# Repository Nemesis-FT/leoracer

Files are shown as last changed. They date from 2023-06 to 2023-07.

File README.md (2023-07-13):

# leoracer
> Now [THIS](https://youtu.be/8bLkcCZFKvA) Is Podracing

[See the controller in action!](https://youtu.be/5lz1fPlmYiA)
Alt The leoracer controller, ready to be used

Leoracer is a making project that aims to create an alternative game controller for the now long forgotten [Pod Racer Game](https://en.wikipedia.org/wiki/Star_Wars_Episode_I:_Racer) developed by LucasArts and recently made available for modern Windows machines through [GoG](https://www.gog.com/en/game/star_wars_episode_i_racer).  
The controller features a double airplane-throttle layout, which can tilt forwards (thus handling the pod's thrust) and tilt sideways (thus handling the pod's tilting): in order to turn left, the player has to reduce throttle to the right side, and vice versa.  
All of this is to provide a more "realistic" control scheme through a D-Input compliant controller, and this is achieved by using the great [ArduinoJoystickLibrary](https://github.com/MHeironimus/ArduinoJoystickLibrary) created by Matthew Heironimus. Kudos to him for the great work he's done on this library. 

This project has been developed for the course "Laboratory of Making" taught by Professor Renzo Davoli and Professor Federico Montori at the University of Bologna, Alma Mater Studiorum.

## Required components
The provided links are provided just for guidance in part-picking. I am not affiliated with "futuranet" or other vendors and I'm not sponsoring them in any way, it's just the store that I used for this project to gather parts.
* An Arduino Leonardo and the Arduino IDE;
* At least 4 variable resistors (I highly suggest you buy spares just in case you damage them during soldering) like this [one](https://futuranet.it/prodotto/potenziometro-lineare-1-kohm/);
* 2 arcade-style buttons like this [one](https://futuranet.it/prodotto/pulsante-arcade-corto-blu/);
* 1 button like this [one](https://futuranet.it/prodotto/pulsante-da-pannello-normalmente-aperto-nero/);
* 1 toggle switch like this [one](https://futuranet.it/prodotto/deviatore-on-on-a-levetta-cs-90/);
* Male to male patch wires and male to female patch wires;
* Some electrical wires;
* PCBs terminal blocks;
* M3 screws of different lenghts;
* M3 brass screw sockets;
* 9 suction cups like this [ones](https://www.amazon.it/dp/B084BRH8GP?psc=1&ref=ppx_yo2ov_dt_b_product_details);
* Soldering equipment;
* A multimeter for troubleshooting;
* A 3D printer or a friend with a 3D printer.

## Building the controller
1. Print all the parts, keeping in mind that the two sides share all the components except for the external shell (BodyR and BodyL). I've used a Lotmaxx SC-10 Shark with some random PLA and all of them have printed nicely;
2. Solder all the components to jumper/patch wires, and embed the brass sockets in the prints using the solderer;
3. Assemble all the parts according to the [animation](https://drive.google.com/file/d/1N2wPsxAuo81091dKuf4QRvu4FyjoekB1/view?usp=sharing), which does not include assembly of the buttons, screws and corresponding sockets.;
4. Connect all the wires to the arduino accordingly to the electrical schema;
5. Flash the Arduino Leonardo with the calibration software: to calibrate the controller, move the axises from minimum to maximum in this order: Right Throttle, Right Tilt, Left Tilt, Left Throttle (after each movement, press the right throttle button);
6. Flash the Arduino Leonardo with the firmware, hopefully you should see your controller on your PC (remember to download and add to Arduino IDE the [ArduinoJoystickLibrary](https://github.com/MHeironimus/ArduinoJoystickLibrary)).

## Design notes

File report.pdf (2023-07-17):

July 13, 2023

# Leoracer

Lorenzo Balugani
Master's Degree student @ Alma Mater Studiorum - University of Bologna

## Contents

## 1 Introduction

This document serves as the project report for the Leoracer project, which was created for the Alma Mater Studiorum’s “Laboratory of Making” course, held by Professor Renzo Davoli and Professor Federico Montori in 2023.

This report will contain information pertinent to the project, such as the problem description, the implementation and development process description and the summary of the issues that have arisen during the project lifecycle. Additionally, it will contain a section all about future improvements.

Special thanks to Matthew Heironimus for his joystick library [2], that was key in the development of this project.

## 2 The problem and the solution

This project aims at solving a very specific and obscure issue that may be of not a lot of interest to many, but it’s still an useful exercise as a first project that involves electronics, 3D design and 3D printing.

Leoracer is a purpose made controller that aims to make available to everyone that possesses the correct equipment to experience the arcade version of the videogame “Star Wars Episode 1: Racer”: the arcade machine wasn’t extremely widespread when it was created, and as time passes it has become more and more rare.

Before going too much in depth, let’s understand what’s the game about in the first place, and what made the arcade version stand out. In the game, the player controls one of the several “Pod Racers” in different races around the galaxy, hence this game behaves for the most part as a racing game. The pod racers are vehicles propelled by several engines, and canonically they “turn” by lowering the thrust of half of the engines, like an airplane moving on the ground. Other than turning, the pod racers can tilt on their axis and pull their nose up or down to better handle air time.

In the computer release and on the console ones, the control over the pod is provided by keyboard, mouse or the analog sticks of the controller. In the arcade version, as portrayed in [1], the user is given two throttle controls that can be manipulated in order to make the vehicle change direction, being the key stand-out feature of the arcade release, along with better graphics.

Leoracer was hence developed in order to bring this control scheme to the PC release, while trying to improve the original product. Leoracer’s throttle control can tilt forwards/backwards and sideways, allowing the user to not just control the thrust and the direction, but also the pod racer’s tilt. The controller features 3 buttons, one of which is also mapped as the combination of both throttle buttons and a toggle, that allows the control of the pod’s orientation.

## 3 Developing the solution

### 3.1 3D Modeling

In order to create such a particular controller, a custom model was needed. The design was made using Solidworks, a powerful parametric CAD software aimed at mechanical 3D modeling. Using Solidworks allowed, through its constraints system, to test the design before printing: this allowed the resolution of many issues before printing the components, and guaranteed the alignment of screw holes and etcetera.

The main inspiration for the controller was a radio transmitter for RC planes, that had two analog sticks that behaved in the desired way. The final design is basically a cylinder with a missing section of its surface, allowing the throttle to be mounted on a potentiometer - allowing it to tilt in all the needed directions.

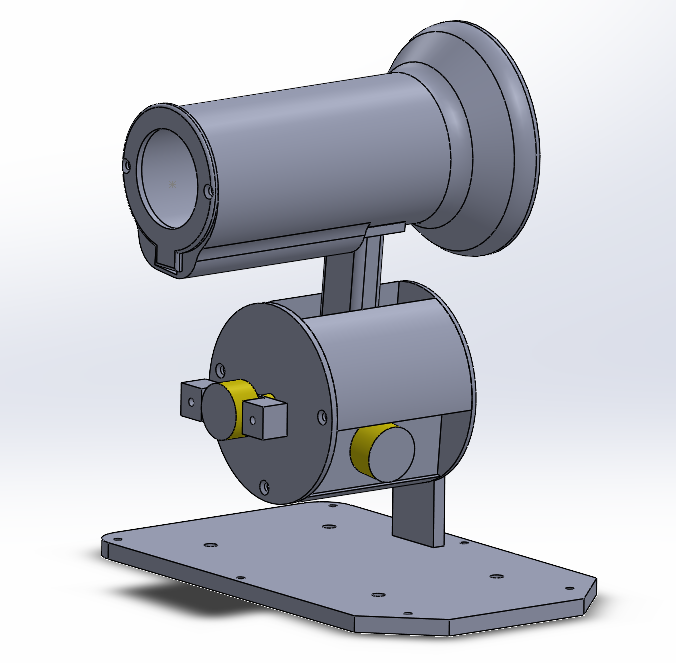
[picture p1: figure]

Figure 1: The rotating cylinder of the throttle

The cylinder is held in place both by the potentiometer that handles forward tilting - which attaches to the external case - and a holder that sits on top of the bottom of the controller.

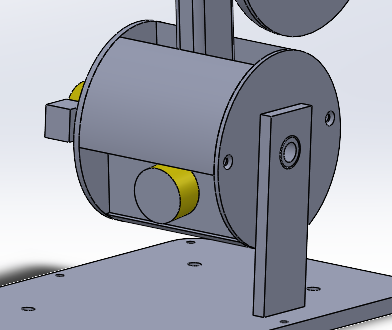
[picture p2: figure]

Figure 2: The support for the rotating cylinder

The throttle is made of two components: the “stick” and the “handle” itself. Both allow a wire to be routed inside of them, which will connect to the button placed inside the handle, and exit from the cylinder using the hole that can be seen fn figure 2. The staff is locked in place by a screw, that is inserted on the larger side of the handle.

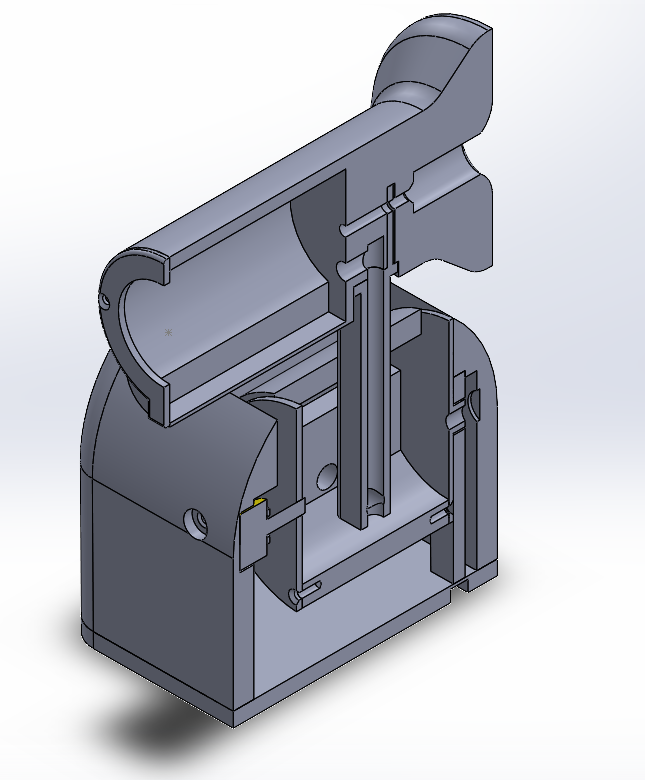
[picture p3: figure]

Figure 3: A slice of the controller, showing the button’s wire channel

Due to the nature of the controller, two throttles will be needed. These are symmetrical internally, while externally they have a slightly different case.

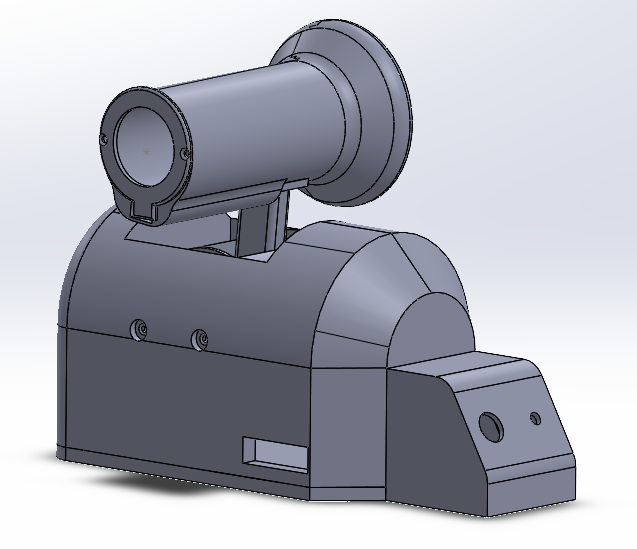
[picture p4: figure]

Figure 4: The right part of the controller

The Arduino Leonardo can fit inside the case of the right part of the controller.

### 3.2 3D Printing

All the parts were printed on a Lotmaxx SC-10 Shark, a FDM 3D printer. In order to make all components stick together, brass screw inserts were embedded - with the help of a soldering iron - in the provided holes of all the prints, and M3 screws were used. The controller is held in place on the table by small suction cups.

### 3.3 Circuit design

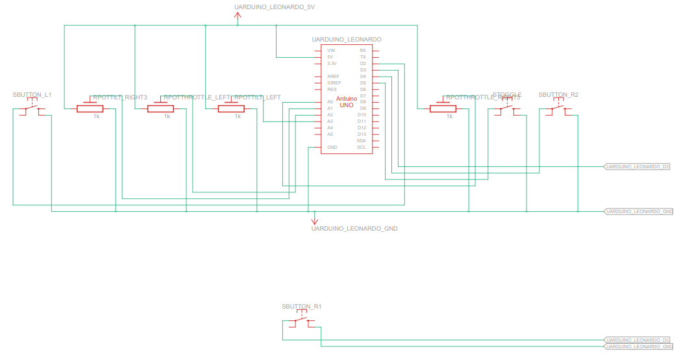
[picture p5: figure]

Figure 5: The schema of the controller

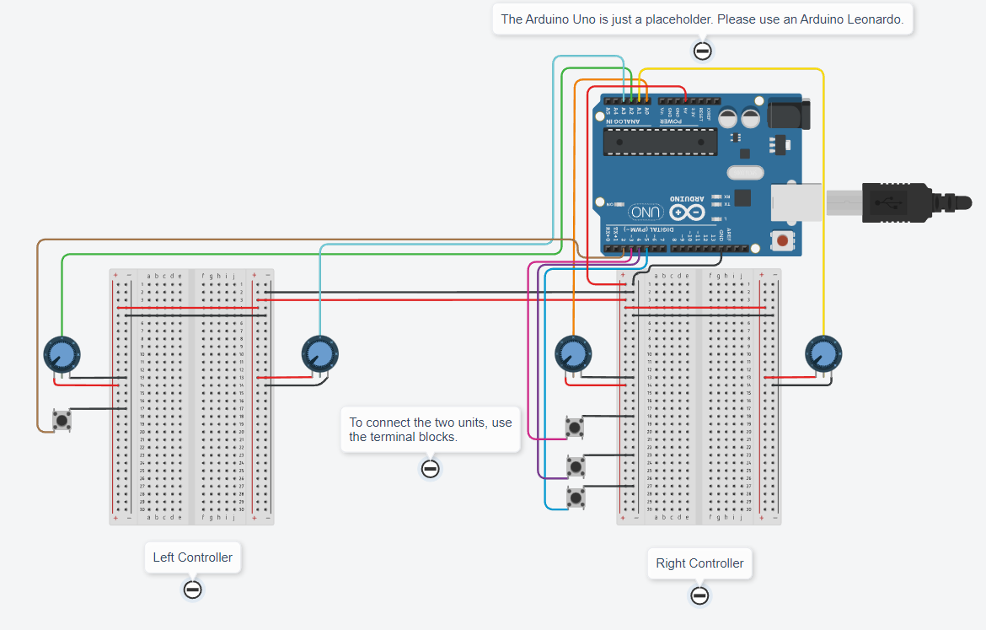
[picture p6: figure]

Figure 6: An intuitive version of the schema

The circuit requires to solder just the buttons, the resistors and the terminal blocks that connect the two parts, and all other connections can be made using jumper wires and breadboards. Additionally, a custom cable needs to be made to connect both parts of the controller. Since the Arduino is configured with INPUT_PULLUP, the buttons do not require resistors to properly work.

### 3.4 Firmware development

Two different pieces of firmware have been developed: the main firmware, which is the one that interfaces with a PC as a D-Input device, and the calibrator, which assists with the calibration routine.

### 3.4.1 Calibrator

The calibrator allows the user to calibrate the controller by placing one axis at a time at its maximum or minimum, then pressing the right throttle button. The calibration data gets then saved to the EEPROM, and will get loaded by the controller firmware. The calibration order is at it follows:
1. Right Throttle (Min/Max).
2. Right Tilt (Min/Max).
3. Left Tilt (Min/Max).
4. Left Throttle (Min/Max).

### 3.4.2 Controller

The controller firmware hevily relies on the Arduino Joystick Library [2], that allows him to act as any D-Input controller, with many customizable parameters. The firmware loads calibration data from the EEPROM, and then uses it to map each axis to a percentage. The axis are evaluated as it follows:
- X-Axis (turning): percentages of the two throttle potentiometers are subtracted, and the resulting value gets passed as the value of the X axis;
- Y-Axis (attitude): the toggle status gets evaluated, and Y is set to the maximum or the minimum, accordingly;
- Z-Axis (throttle): the highest percentage of the two throttle potentiometers gets used;

For tilting, two buttons (4 and 5) are used, since the game consideres it a discrete value. If the two tilt controls have a percentage lower than 15 (or higher than 85), the corresponding button gets pressed.

## 4 Using the controller

Once built and calibrated, the controller is straightforward to use, as it gets picked up as a standard D-Input controller. The buttons can be bound ingame without much of an issue. A video of the game being played with the controller can be seen on Youtube [3].

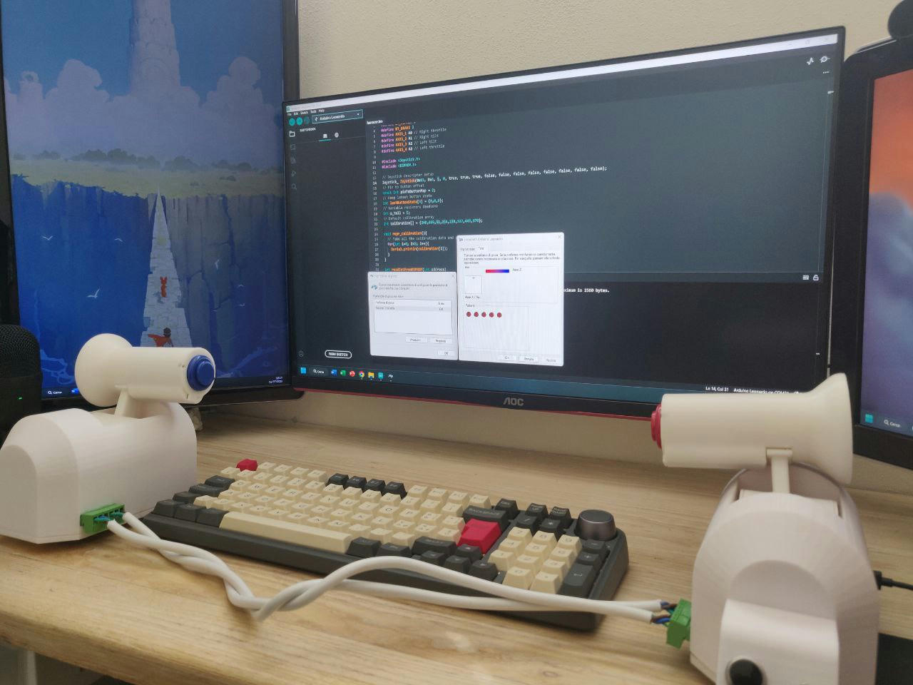
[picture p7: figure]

Figure 7: The Leoracer Controller

## 5 Project availability

The project is available under the GPL v3 license on the github repository [4]. The readme contains a detailed parts list and a set of instruction for assembly.

## 6 Challenges

This project was the first experience with developing from scratch and printing a complex model that had to accomplish some mechanical challenges. It also was the first project that involved soldering and - in general - electronics.

## 7 Known issues

- Due to how the in-race menu works, it’s not possible to control it using the keyboard, as it’s meant to be controlled by the Y axis of the controller. In order to regain control, press CTRL+J to momentarely disable controller input.
- Suction cups do not work on all surfaces.

## 8 Future improvements

The controller, as is, works great. However, several improvements could be made in a future revision, such as:
- Encoders instead of potentiometers, providing better accuracy and longevity.
- More buttons on the throttle handles, in order to increase button count.
- Stiffer throttle tilting, perhaps achieved using springs.
- Reduced bulkyness of the case.
- An optional mountuing system to allow the controller to stick to any surface.

## Bibliography

[1] Dr. Retro. Star Wars Episode 1 Arcade Racer Cabinet Gameplay, (2014). [Online Video]. Available: https://www.youtube.com/watch?v=g0bF3kAVur4
[2] Matthew Heironimus, “Arduino joystick library.” [Online]. Available: https://github.com/MHeironimus/ArduinoJoystickLibrary (https://github.com/MHeironimus/ArduinoJoystickLibrary)
[3] Lorenzo Balugani. Star Wars Episode 1 Racer With a Custom Controller, (2023). [Online Video]. Available: https://www.youtube.com/watch?v=g0bF3kAVur4
[4] Lorenzo Balugani, “Leoracer repository.” [Online]. Available: https://github.com/Nemesis-FT/leoracer (https://github.com/Nemesis-FT/leoracer)

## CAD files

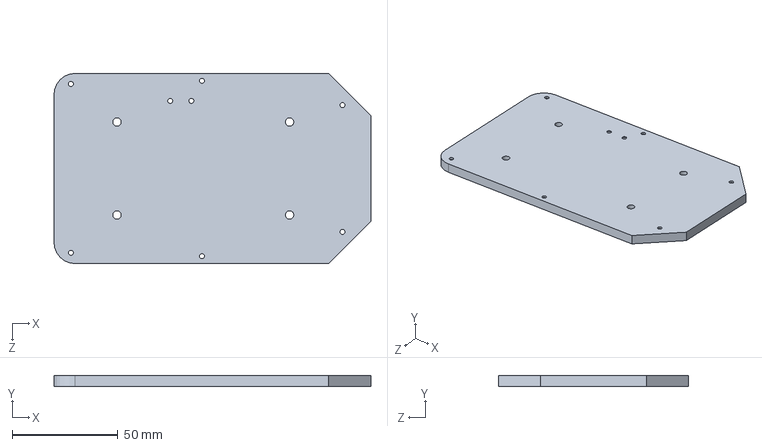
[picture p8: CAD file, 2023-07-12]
cad files/Base.SLDPRT
150.0 x 5.00 x 90.0 mm

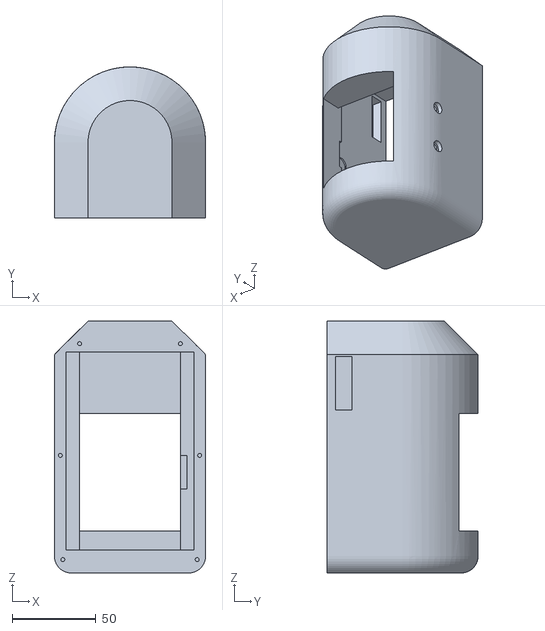
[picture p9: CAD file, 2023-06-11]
printables/BodyL.STL
90.0 x 90.0 x 150.0

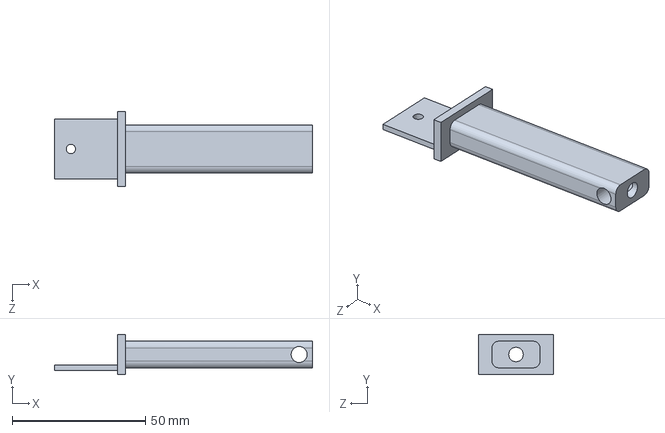
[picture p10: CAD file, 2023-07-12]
cad files/Staffa.SLDPRT
96.7 x 15.0 x 28.0 mm

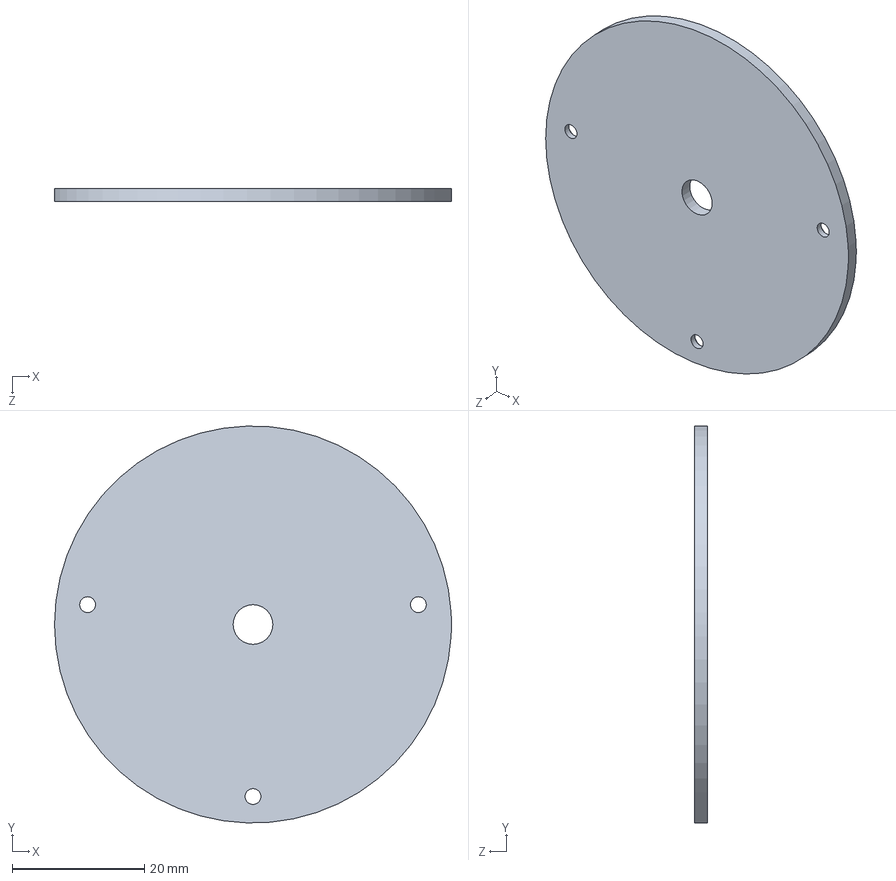
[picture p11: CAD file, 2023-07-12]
cad files/RollerTappo.SLDPRT
60.0 x 60.0 x 2.00 mm

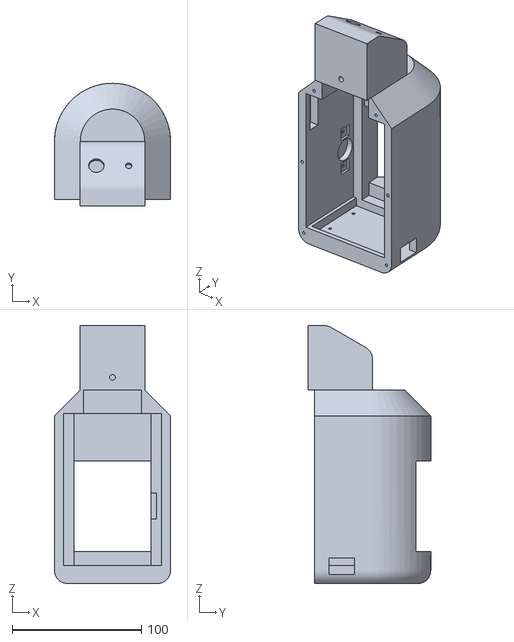
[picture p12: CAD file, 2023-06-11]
printables/BodyR.STL
90.0 x 95.0 x 200.0

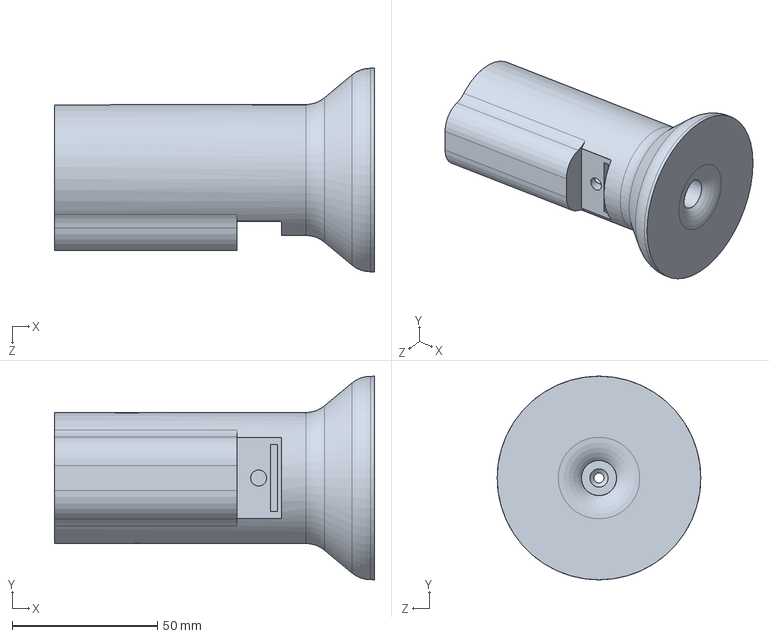
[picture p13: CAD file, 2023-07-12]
cad files/Handle.SLDPRT
110.0 x 70.0 x 70.0 mm

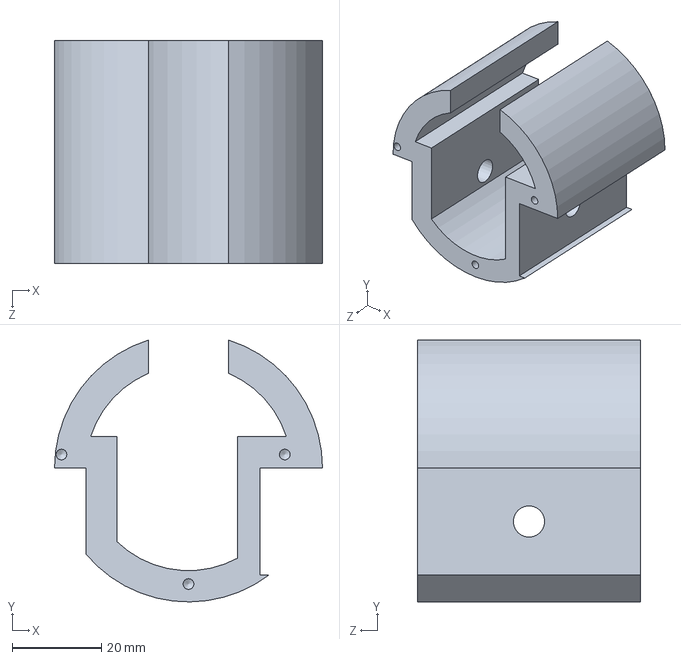
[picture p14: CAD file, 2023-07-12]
cad files/Rollerv2.SLDPRT
60.0 x 58.6 x 50.0 mm

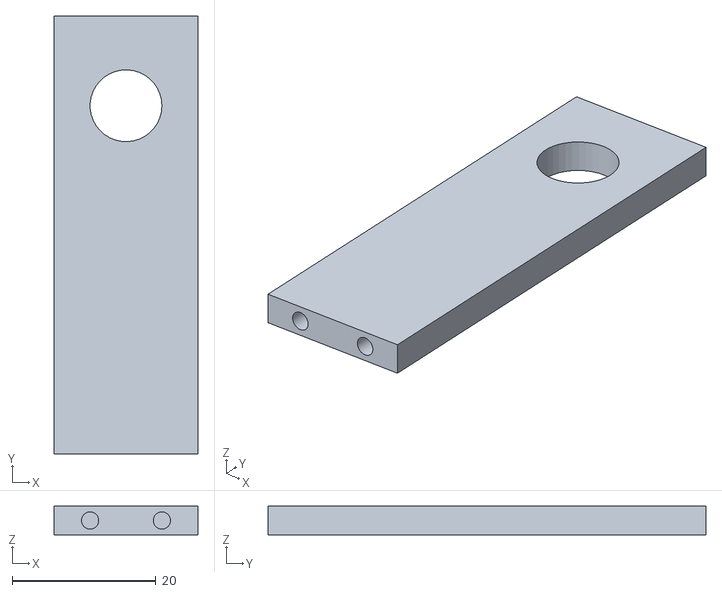
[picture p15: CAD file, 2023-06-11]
printables/BodyPilastrino.STL
20.0 x 61.0 x 4.00

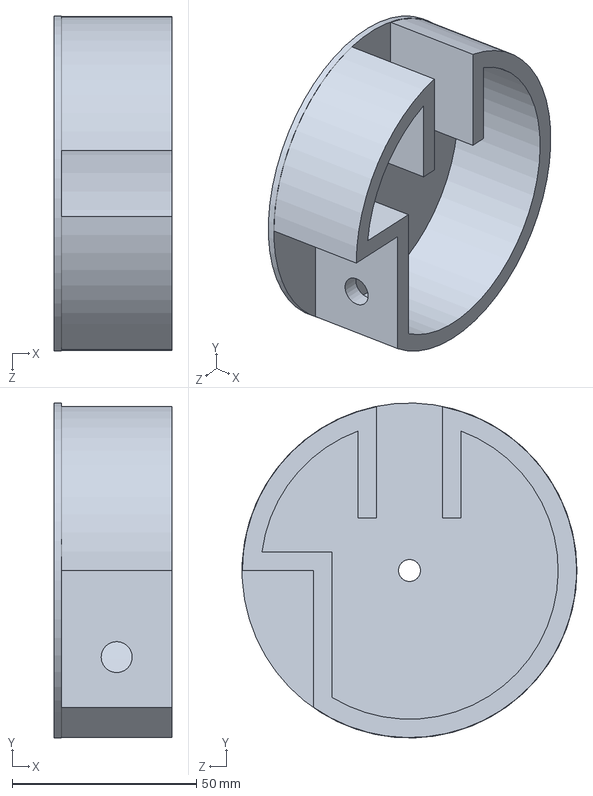
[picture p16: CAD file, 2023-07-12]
cad files/Roller.SLDPRT
32.0 x 91.0 x 91.0 mm

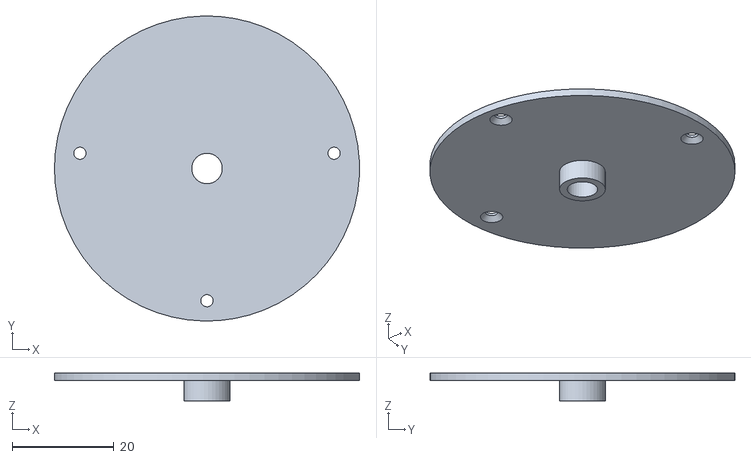
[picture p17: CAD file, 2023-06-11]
printables/RollerTappo2.STL
60.0 x 60.0 x 5.50

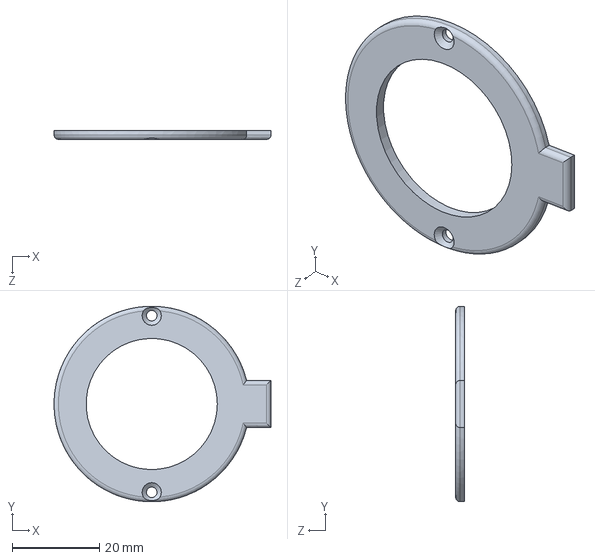
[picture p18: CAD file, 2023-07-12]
cad files/HandleButtonHolder.SLDPRT
49.6 x 44.7 x 2.00 mm

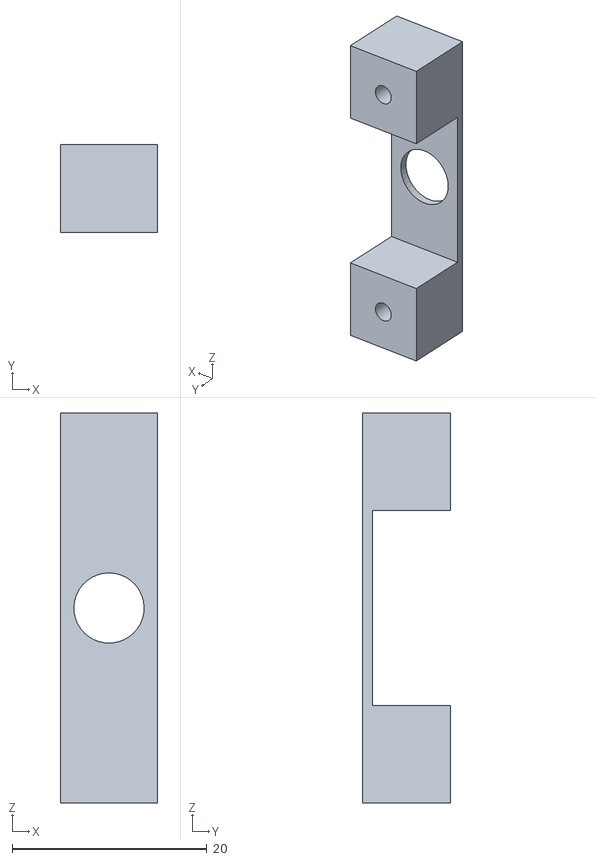
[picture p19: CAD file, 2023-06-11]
printables/HolderResistore.STL
10.0 x 9.00 x 40.0

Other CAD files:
printables/Base.STL
printables/Staffa.STL
printables/Rollerv2.STL
cad files/Bodyl.SLDPRT
cad files/HolderResistore.SLDPRT
printables/HandleButtonHolder.STL
cad files/ArduinoLeonardo.SLDPRT
cad files/Body.SLDPRT
cad files/BodyPilastrino.SLDPRT
cad files/RollerTappo2.SLDPRT
printables/Handle.STL
printables/RollerTappo.STL

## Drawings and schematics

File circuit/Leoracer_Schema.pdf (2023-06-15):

A

1 | 2 | 3 | 4 | 5 | 6

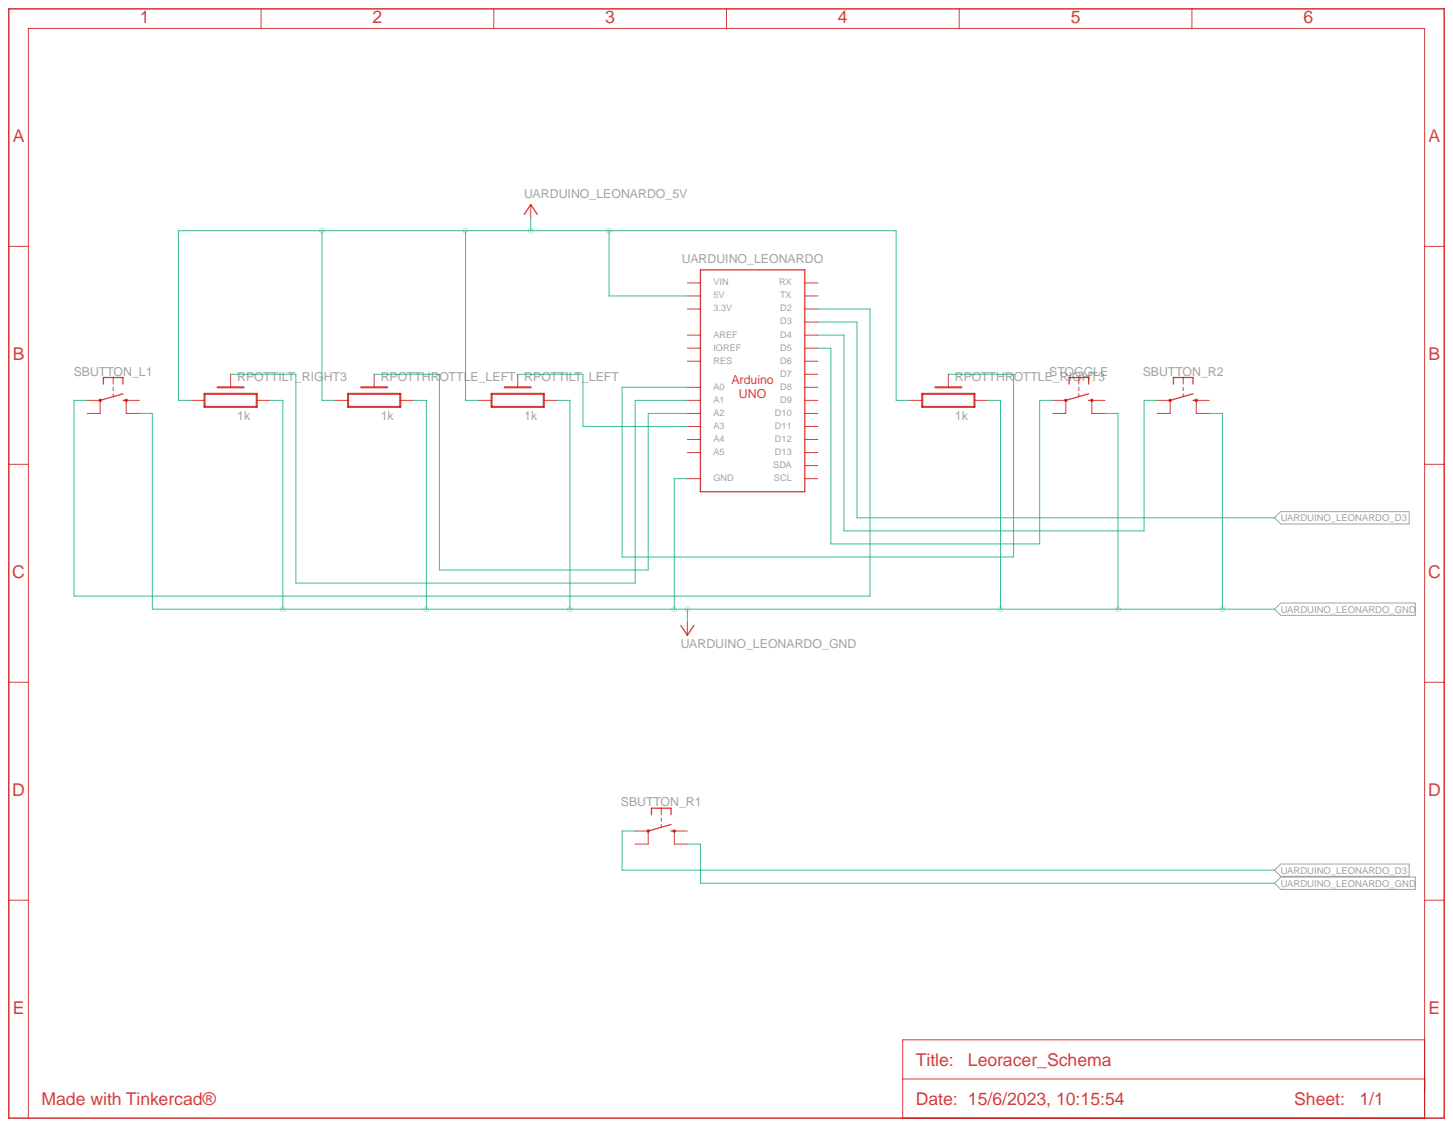
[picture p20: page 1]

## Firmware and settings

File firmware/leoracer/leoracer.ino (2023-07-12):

#define BT_TOGGLE 5
#define BT_WARP 4
#define BT_REPAIR 3
#define BT_BRAKE 2
#define AXIS_1 A0 // Right throttle
#define AXIS_2 A1 // Right tilt
#define AXIS_3 A2 // Left tilt
#define AXIS_4 A3 // Left throttle

#include <Joystick.h>
#include <EEPROM.h>

// Joystick descriptor setup
Joystick_ Joystick(0x03, 0x4, 5, 0, true, true, true, false, false, false, false, false, false, false, false);
// Pin to Button offset
const int pinToButtonMap = 2;
// Keep latest button state
int lastButtonState[4] = {0,0,0};
// Variable resistors deadzone
int p_toll = 5;
// Default calibration array
int calibration[] = {240,440,55,254,150,327,449,670};

void repr_calibration(){     
  // Take all the calibration data and print it out         
  for(int i=0; i<8; i++){
    Serial.println(calibration[i]);
  }
}

int readIntFromEEPROM(int address)
{
  // Read two bytes from the starting address
  byte byte1 = EEPROM.read(address);
  byte byte2 = EEPROM.read(address + 1);
  return (byte1 << 8) + byte2;
}


void read_calibration(){
  // Calibration loader
  Serial.println("Attempting data load from EEPROM...");
  int tmp;
  for(int i=0; i<16; i=i+2){
    calibration[i/2] = readIntFromEEPROM(i);;
  }
  Serial.println("Calibration data loaded from EEPROM.");
  repr_calibration();
}

void setup() {
  // I/O setup
  pinMode(BT_WARP, INPUT_PULLUP);
  pinMode(BT_REPAIR, INPUT_PULLUP);
  pinMode(BT_TOGGLE, INPUT_PULLUP);
  pinMode(BT_BRAKE, INPUT_PULLUP);
  pinMode(AXIS_1, INPUT);
  pinMode(AXIS_2, INPUT);
  pinMode(AXIS_3, INPUT);
  pinMode(AXIS_4, INPUT);
  Serial.begin(9600);
  delay(1000);
  read_calibration();
  Joystick.setXAxisRange(-100, 100);
  Joystick.setYAxisRange(0, 1);
  Joystick.setZAxisRange(0, 100);
  Joystick.begin();
}

void handle_buttons(){
  // Button handling function, with override for button doublepress
  bool override = false;
  // Get the state
  for (int index = 0; index < 3; index++)
  {
    int currentButtonState = !digitalRead(index + pinToButtonMap);
    if (currentButtonState == HIGH)
    {
      
      lastButtonState[index] = currentButtonState;
    }
    else{
      
      lastButtonState[index] = currentButtonState;
    }
  }
  // Apply the state
  for(int index = 0; index < 3; index++){
    if(index == 0 && lastButtonState[0] && lastButtonState[1]){
      Joystick.setButton(2,1);
      Joystick.setButton(1,0);
      Joystick.setButton(0,0);
      override = true;
      break;
    }
    else{
      Joystick.setButton(index, lastButtonState[index]);
    }
    
  }
}

int to_percent(int min, int max, int value){
  // map the value to a percentage
  return map(value, min, max, 0, 100);
}

int handle_y(){
  // handle Y axis (which is considered as on/off since its wired to a toggle)
  int currentButtonState = !digitalRead(BT_TOGGLE);
  if (currentButtonState)
  {
    return 1;
  }
  return 0;
}

int handle_x(int perc_l, int perc_r){
  // handle X axis by comparing percentage of the throttles
  if(perc_l-p_toll < perc_r && perc_l+p_toll > perc_r){
    return 0;
  }
  else if (perc_r-p_toll < perc_l && perc_r+p_toll > perc_l){
    return 0;
  }
  return (perc_l - perc_r);
}

int handle_throttle(int perc_l, int perc_r){
  // Get the highest throttle value among the throttles
  if(perc_l>perc_r){
    return perc_l;
  }
  else{
    return perc_r;
  }
}

void handle_ry(int perc_l, int perc_r){
  // Handle the rotation, done by using buttons instead of axis
  if(perc_l < 15 && perc_r < 15){
    Joystick.setButton(3, 1);
  }
  else{
    Joystick.setButton(3, 0);  
  }
  if(perc_l>85 && perc_r > 85){
    Joystick.setButton(4, 1);
  }
  else{
    Joystick.setButton(4, 0);
  }
}

void handle_axis(){
  // axis handling routine
  int r_thr = to_percent(calibration[0], calibration[1], analogRead(AXIS_1));
  int r_til = to_percent(calibration[2], calibration[3], analogRead(AXIS_2));
  int l_til = to_percent(calibration[4], calibration[5], analogRead(AXIS_3));
  int l_thr = to_percent(calibration[6], calibration[7], analogRead(AXIS_4));
  // Calculate X axis according to throttle level on both sides;
  int x_axis = handle_x(l_thr, r_thr);
  // Calculate Y axis according to toggle status;
  int y_axis = handle_y();
  // Calculate throttle by selecting the highest throttle level;
  int throttle = handle_throttle(l_thr, r_thr);
  // Calculate ry axis according to tilt controls;
  handle_ry(l_til, r_til);
  Serial.println("======");
  Serial.println(r_til);
  Serial.println(l_til);
  Joystick.setXAxis(x_axis);
  Joystick.setYAxis(y_axis);
  Joystick.setZAxis(throttle);
}

void loop() {
  // Work with buttons, then with axis
  handle_buttons();
  handle_axis();
  delay(50);
}

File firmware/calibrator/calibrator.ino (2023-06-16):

#define AXIS_1 A0 // Right throttle
#define AXIS_2 A1 // Right tilt
#define AXIS_3 A2 // Left tilt
#define AXIS_4 A3 // Left throttle
#define BT_NEXT 2 // Right button

#include <EEPROM.h>
// Current state
int status = 0;
// Calibration vector
int calibration[] = {0,255,0, 255,0, 255,0, 255};
// Pins of the analog sources
int pins[] = {A0, A1, A2, A3};


void setup() {
  // I/O Setup
  pinMode(AXIS_1, INPUT);
  pinMode(AXIS_2, INPUT);
  pinMode(AXIS_3, INPUT);
  pinMode(AXIS_4, INPUT);
  pinMode(BT_NEXT, INPUT_PULLUP);
  Serial.begin(9600);
  // Erase the eeprom
  for (int i = 0 ; i < EEPROM.length() ; i++) {
    EEPROM.write(i, 0);
  }
  Serial.println("All data erased. Ready for calibration.");
}

void repr_calibration(){
  // Print the contents of the calibration vector
  for(int i=0; i<8; i++){
    Serial.println(calibration[i]);
  }
}

void read_calibration(){
  // Try to read the calibration data
  Serial.println("Attempting data load from EEPROM...");
  int tmp;
  for(int i=0; i<16; i=i+2){
    calibration[i/2] = readIntFromEEPROM(i);;
  }
  Serial.println("Calibration data loaded from EEPROM.");
  repr_calibration();
}

void writeIntIntoEEPROM(int address, int number)
{ 
  // 2 bytes are needed in order to properly store an integer
  byte byte1 = number >> 8;
  byte byte2 = number & 0xFF;
  EEPROM.write(address, byte1);
  EEPROM.write(address + 1, byte2);
}

int readIntFromEEPROM(int address)
{
  // Read an int from a starting address
  byte byte1 = EEPROM.read(address);
  byte byte2 = EEPROM.read(address + 1);
  return (byte1 << 8) + byte2;
}

void save(){
  // Save calibration data
  for(int i=0; i<16; i=i+2){
    writeIntIntoEEPROM(i, calibration[i/2]);
  }
  Serial.println("Saved calibration data to EEPROM.");
}

void loop() {
  // Calibrate the axis one by one
  if(!digitalRead(BT_NEXT) && status <8){
    calibration[status] = analogRead(pins[status/2]);
    status+=1;
    Serial.println("OK");
    delay(1000);
  }
  if(status==8){
    // Saving state, then deadlock
    repr_calibration();
    save();
    status+=1;
    delay(1000);
    read_calibration();
  }
}

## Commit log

2023-06-09 :sparkles: Calibration and Firmware
    First draft for the firmware of the controller.
2023-06-10 :bug: Fixed minor issues
    Fix error in tilt handling function.
    [leoracer.ino]
2023-06-11 :sparkles: Calibration save functionality
    Now the calibration firmware can save to EEPROM the calibration data.
2023-06-11 :sparkles: Add printables
    Printables section
    [Base.STL, BodyL.STL, BodyPilastrino.STL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]
2023-06-15 :sparkles: Circuit layout documentation
    [Leoracer_Schema.brd]
2023-06-15 :bug: Fix issue with tilt controls
    [leoracer.ino]
2023-07-12 Add cad files
    [ArduinoLeonardo.SLDPRT, Base.SLDPRT, Body.SLDPRT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]
